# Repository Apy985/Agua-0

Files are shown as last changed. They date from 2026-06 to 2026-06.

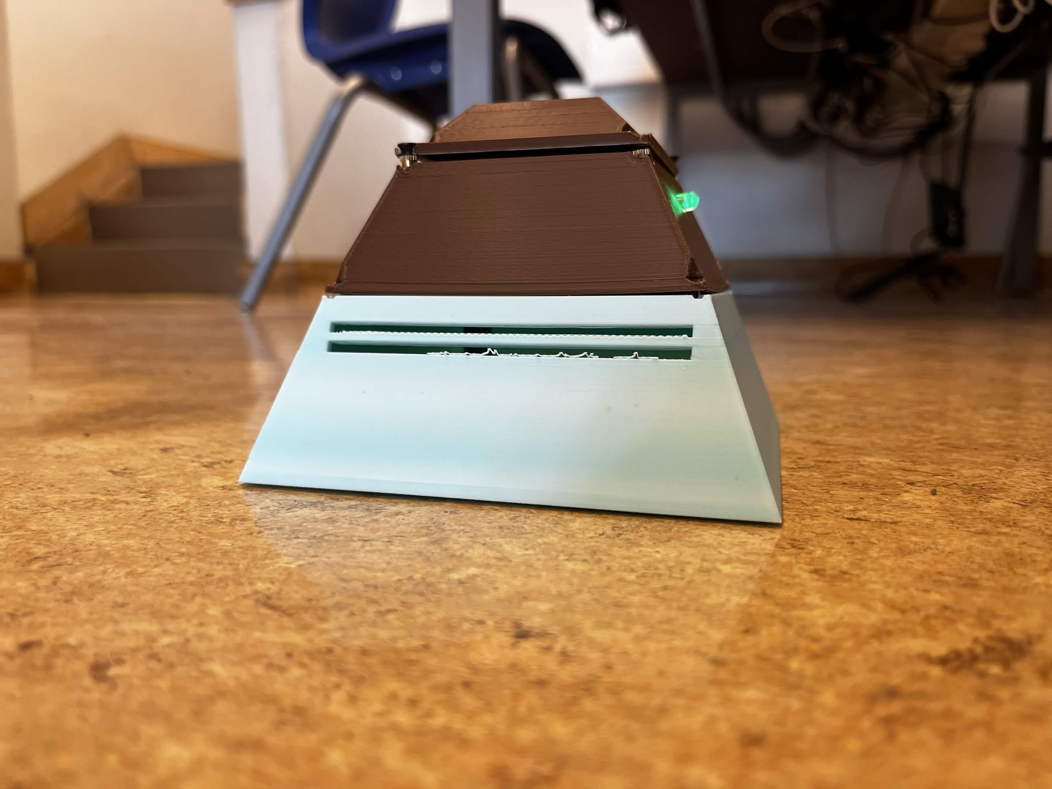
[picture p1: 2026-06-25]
hardware/fotos/imagen ´prototipo 3.jpg

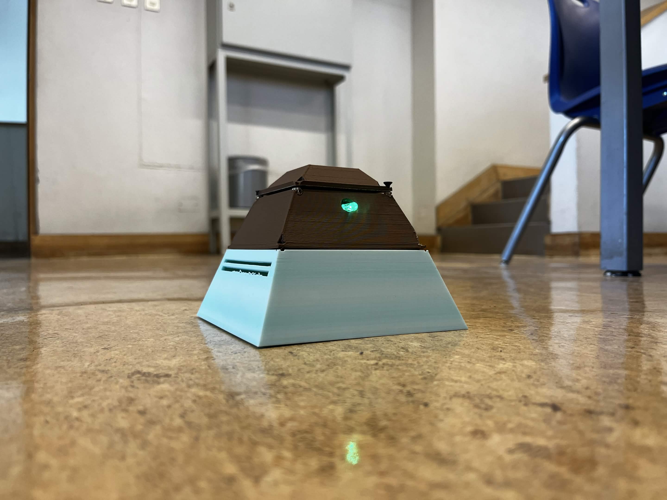
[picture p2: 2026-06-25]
hardware/fotos/imagnen prototipo 2.jpg

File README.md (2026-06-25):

# Agua-0 — Sistema de Monitoreo de Humedad Urbana

Sistema IoT de bajo costo para detectar zonas con riesgo de desbordamiento de aguas en la vía pública, mediante una red de sensores de nivel de agua distribuidos por sectores urbanos.

## Integrantes
- Martín Román *(Líder de proyecto)*
- José Tomás Said
- Matías González
- Sebastián Romero

**Curso:** TEI201 — Taller de Diseño en Ingeniería · UAI · 2026 Semestre 1

---

## Problema que resuelve

En sectores urbanos de Santiago, las lluvias intensas generan acumulación de agua en la vía pública sin que exista un sistema de alerta temprana. Agua-0 permite monitorear en tiempo real el nivel de humedad por sector, identificar zonas críticas y tomar decisiones preventivas antes de que ocurra el desbordamiento.

---

## Arquitectura del sistema

```
[ESP32-S3 Super Mini]  →  ESP-NOW  →  [ESP8266 MOD]  →  WiFi HTTPS  →  [Supabase]  →  [Dashboard Vercel]
     (sensor + LED)                      (gateway)                      (base de datos)     (visualización)
```

---

## Componentes de hardware

| Componente | Especificación | Cantidad |
|---|---|---|
| Microcontrolador sensor | ESP32-S3 Super Mini | 1 |
| Gateway WiFi | ESP8266 MOD | 1 |
| Sensor de nivel de agua | Sensor nivel de agua FZ0506 5-5V esp32 Arduino | 1 |
| LED RGB | Cátodo común | 1 |
| Batería | LiPo AHB623450 3.7V ~1200mAh | 1 |

---

## Estructura del repositorio

```
agua-0/
├── README.md
├── FUENTES.md
├── firmware/
│   ├── Codigo_esp32-s3_final.ino   # Firmware nodo sensor
│   ├── Codigo_esp8266.ino          # Firmware gateway WiFi
│   └── dashboard/
│       └── index.html              # Dashboard web
├── hardware/
│   ├── esquematico.png             # Diagrama de conexiones (Wokwi)
│   ├── BOM.md                      # Lista de materiales con costos
│   └── fotos/                      # Fotografías del prototipo
├       ├── imagen prototipo 1.jpg         imagen prototipo 1.jpg                
│       ├── imagen prototipo 2.jpg                     
│       └── imagen prototipo 3.jpg     
├── diseño-3d/
│   ├── encapsulado.f3d             # Modelo Fusion 360
│   ├── planos.pdf                  # Planos técnicos con cotas
│   └── renders/                    # Renders del Encapsulado             
│       ├── render_exterior.png
│       ├── render_cuerpo_1.png
│       ├── render_cuerpo_2.png
│       └── render_cuerpo_3.png
├── testing/
│   └── protocolo_pruebas.md        # Protocolo y resultados de pruebas
└── docs/
    └── reporte_final.pdf
```

---

## Instrucciones para replicar el firmware

### Requisitos
- Arduino IDE 2.x
- Board: ESP32 by Espressif (versión 3.3.8) para el ESP32-S3
- Board: ESP8266 by ESP8266 Community para el ESP8266

### Librerías necesarias
- `esp_now.h` — incluida en el SDK ESP32
- `ESP8266HTTPClient.h` — incluida en el SDK ESP8266
- `WiFiClientSecureBearSSL` — incluida en el SDK ESP8266

### Pasos
1. Clonar este repositorio
2. Abrir `firmware/Codigo_esp32-s3_final.ino` en Arduino IDE
3. Seleccionar placa: **ESP32S3 Dev Module**
4. Cargar el firmware al ESP32-S3
5. Abrir `firmware/Codigo_esp8266.ino`
6. Reemplazar `TU_RED_WIFI` y `TU_PASSWORD` con las credenciales reales
7. Seleccionar placa: **Generic ESP8266 Module**
8. Cargar el firmware al ESP8266

### Conexiones ESP32-S3
| Componente | Pin ESP32-S3 |
|---|---|
| Sensor S (señal) | GPIO 4 |
| Sensor VCC | 3.3V |
| Sensor GND | GND |
| LED R | GPIO 2 |
| LED G | GPIO 3 |
| LED B | GPIO 5 |
| LED GND | GND |

---

## Dashboard

**URL:** https://agua-0.vercel.app/

El dashboard muestra en tiempo real:
- Humedad por sector con indicador de alerta
- Cinta de alertas animada para sectores sobre 80%
- Pronóstico climático de Santiago vía Open-Meteo
- Calendario de lluvias del mes actual
- Tendencia histórica con selector 24h / 7 días / 30 días / año
- Comparativa de días en alerta por año

Se actualiza automáticamente cada 30 segundos.

---

## Servicios utilizados

| Servicio | Uso | Plan |
|---|---|---|
| Supabase | Base de datos PostgreSQL en la nube | Gratuito |
| Vercel | Hosting del dashboard web | Gratuito |
| Open-Meteo | API de pronóstico climático | Gratuito |

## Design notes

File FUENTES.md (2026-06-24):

Fuentes · MD
# FUENTES.md — Declaración de Fuentes e IA
## Proyecto: Agua-0 — Sistema de Monitoreo de Humedad Urbana
### TEI201 — Taller de Diseño en Ingeniería · UAI · Junio 2026
 
---
 
## 1. Librerías utilizadas
 
| Librería | Versión | Uso en el proyecto | Fuente |
|---|---|---|---|
| ESP8266WiFi | built-in | Conexión WiFi del nodo gateway ESP8266 | https://github.com/esp8266/Arduino |
| ESP8266HTTPClient | built-in | Envío de datos HTTP POST a Supabase desde ESP8266 | https://github.com/esp8266/Arduino |
| espnow | built-in | Comunicación inalámbrica entre ESP32-S3 y ESP8266 | https://docs.espressif.com/projects/esp-idf/en/latest/esp32/api-reference/network/esp_now.html |
| ArduinoJson | 6.x | Serialización de datos en formato JSON para el POST a Supabase | https://arduinojson.org |
| Chart.js | 4.4.1 | Renderizado de gráficos en el dashboard web | https://cdnjs.cloudflare.com/ajax/libs/Chart.js/4.4.1/chart.umd.js |
 
---
 
## 2. Código externo adaptado
 
### Conexión WiFi con reintentos (gateway ESP8266)
- **Fuente:** https://randomnerdtutorials.com/esp32-useful-wifi-functions/
- **Adaptación:** Se modificó el tiempo de espera entre reintentos de 500ms a 1000ms y se agregó límite de 20 intentos para evitar bucles infinitos en zonas de señal débil.
### HTTP POST a Supabase REST API (gateway ESP8266)
- **Fuente:** Documentación oficial de Supabase REST API — https://supabase.com/docs/guides/api
- **Adaptación:** Se implementaron los headers requeridos (`apikey`, `Authorization: Bearer`, `Prefer: return=minimal`) y se construyó el body JSON con los campos específicos del proyecto.
### Recepción de datos ESP-NOW (gateway ESP8266)
- **Fuente:** Ejemplo oficial de Espressif — https://docs.espressif.com/projects/esp-idf/en/latest/esp32/api-reference/network/esp_now.html
- **Adaptación:** Se adaptó el callback de recepción para extraer el valor de humedad del struct personalizado y acumularlo antes de enviarlo al servidor.
---
 
## 3. Uso de Inteligencia Artificial
 
### Dashboard web completo (`firmware/dashboard/index.html`)
- **Herramienta:** Claude Sonnet 4.6 (Anthropic, junio 2026)
- **Prompt:** *"Crea un dashboard HTML completo conectado a Supabase para monitoreo de humedad urbana. Debe mostrar: métricas por sector, gráfico histórico con selector 24h/7d/30d/año, pronóstico climático desde Open-Meteo para Santiago Chile, calendario de lluvias, gráfico comparativo anual y distribución de lecturas. Incluir cinta de alertas animada para sectores sobre 80%. Diseño oscuro."*
- **Adaptación:** Se ajustaron umbrales (80% desbordamiento, 65% elevado), intervalo de actualización a 30 segundos, y se reescribió usando funciones tradicionales en lugar de async/await para compatibilidad con el entorno de Vercel.
- **Comprensión:** El equipo comprende que el dashboard usa `fetch()` para consultar la API REST de Supabase filtrando por timestamp. Chart.js recibe arrays de labels y datasets. La cinta de alertas usa CSS `animation` con `translateX` para el scroll continuo.
### Estructura de base de datos y queries SQL
- **Herramienta:** Claude Sonnet 4.6 (Anthropic, junio 2026)
- **Prompt:** *"Dame el SQL para crear una tabla lecturas en Supabase con campos sector, timestamp, humedad_pct, llovio y precip_mm. También un INSERT masivo con generate_series para datos históricos de prueba de los últimos 6 meses."*
- **Adaptación:** Se corrigió el constraint de clave primaria, se ajustaron valores de humedad por rango estacional (meses 6-8 más húmedos para simular invierno chileno).
- **Comprensión:** `generate_series` produce timestamps cada 15 minutos; `CASE WHEN` asigna humedad distinta por sector con variación aleatoria mediante `random()`.
### Arquitectura general del sistema IoT
- **Herramienta:** Claude Sonnet 4.6 (Anthropic, junio 2026)
- **Uso:** Definición de la topología ESP32-S3 → ESP-NOW → ESP8266 → WiFi → Supabase, selección del stack gratuito (Supabase + Vercel), y cálculo de autonomía energética.
- **Adaptación:** El equipo validó la arquitectura contra los componentes físicos disponibles y ajustó el flujo según restricciones reales del hardware.
### Reorganización y comentarios del firmware ESP32-S3
- **Herramienta:** Claude Sonnet 4.6 (Anthropic, junio 2026)
- **Uso:** Revisión de estructura del código y mejora de comentarios explicativos por secciones.
- **Adaptación:** Los umbrales (UMBRAL_25 1100, UMBRAL_75 1900) fueron determinados por el equipo mediante calibración física. La MAC del ESP8266 fue obtenida directamente del hardware real.
- **Comprensión:** ESP-NOW requiere modo `WIFI_STA` activo aunque no haya conexión a red. El callback `onSent` es asíncrono. El struct `DatosSensor` se serializa como bytes raw al enviarse.
---
 
## 4. Servicios externos utilizados
 
| Servicio | Uso | URL |
|---|---|---|
| Supabase | Base de datos PostgreSQL en la nube (plan gratuito) | https://supabase.com |
| Vercel | Hosting del dashboard web (plan gratuito) | https://vercel.com |
| Open-Meteo | API de pronóstico climático gratuita para Santiago | https://open-meteo.com |
| Wokwi | Simulador y esquemático del circuito | https://wokwi.com/projects/462681394967646209 |

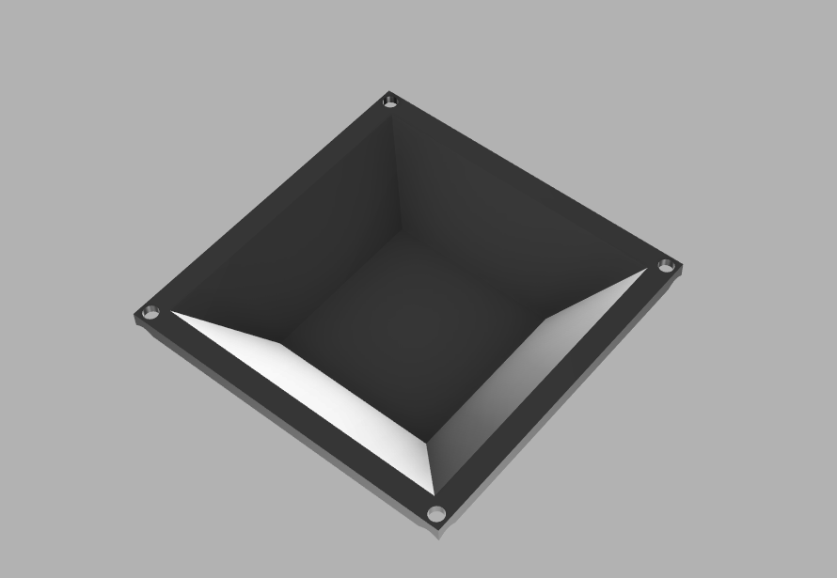
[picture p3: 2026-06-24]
diseño-3d/Renders/render_cuerpo_3.png

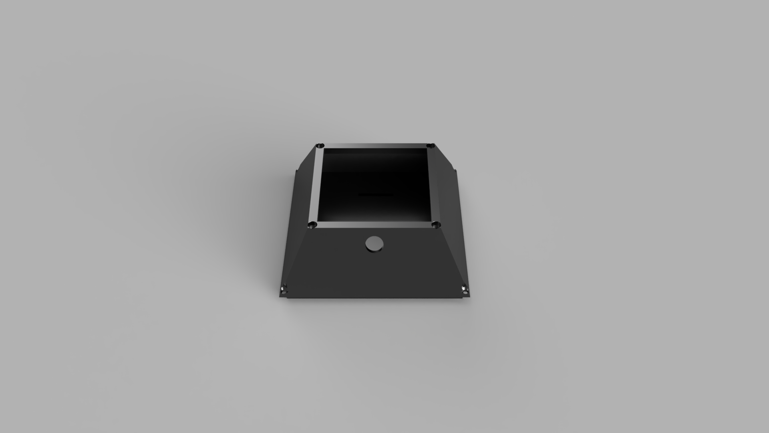
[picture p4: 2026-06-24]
diseño-3d/Renders/render_cuerpo_2.png

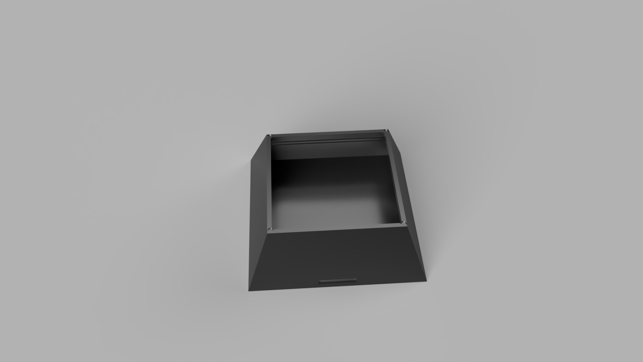
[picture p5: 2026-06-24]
diseño-3d/Renders/render_cuerpo_1.png

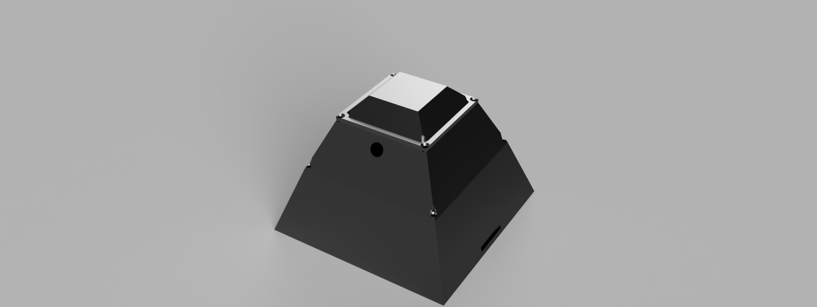
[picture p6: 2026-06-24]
diseño-3d/Renders/render__exterior.png

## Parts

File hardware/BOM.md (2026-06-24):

# BOM — Lista de Materiales
## Proyecto Agua-0 · TEI201 · UAI · 2026

| # | Componente | Especificación | Cantidad | Costo unitario (CLP) | Costo total (CLP) |
|---|---|---|---|---|---|
| 1 | Microcontrolador sensor | ESP32-S3 Super Mini, 16MB Flash, 8MB PSRAM | 1 | $8.500 | $8.500 |
| 2 | Gateway WiFi | ESP8266 MOD, 802.11 b/g/n, 3.3V | 1 | $3.500 | $3.500 |
| 3 | Sensor de nivel de agua | Sensor nivel de agua FZ0506 5-5V esp32 Arduino | 1 | $1.200 | $1.200 |
| 4 | LED RGB | Cátodo común, 5mm, 20mA máx por canal | 1 | $200 | $200 |
| 5 | Batería LiPo | AHB623450, 3.7V, ~1200mAh | 1 | $4.500 | $4.500 |
| 6 | Cables jumper | Macho-macho y macho-hembra, 20cm | 10 | $80 | $800 |
| 7 | Protoboard | 400 puntos | 1 | $1.500 | $1.500 |
| | | | | **TOTAL** | **$20.200** |

---

## Justificación de componentes

**ESP32-S3 Super Mini** — Seleccionado por su bajo consumo en deep sleep (~20µA), soporte nativo para ESP-NOW, ADC de 12 bits para lectura precisa del sensor, y factor de forma compacto compatible con el encapsulado diseñado.

**ESP8266 MOD** — Actúa como gateway WiFi dedicado, separando la responsabilidad de red del nodo sensor. Permite que el ESP32-S3 opere en ciclos de bajo consumo mientras el ESP8266 mantiene la conexión WiFi permanente.

**Sensor de nivel de agua** — Sensor resistivo analógico de bajo costo, suficiente para detectar los 3 umbrales requeridos (bajo/intermedio/alto). Rango de operación 3.3V compatible con el ESP32-S3.

**LED RGB cátodo común** — Indicador visual inmediato del nivel de agua sin necesidad de pantalla. Verde/Amarillo/Rojo mapeado directamente a los 3 umbrales del sistema.

**Batería LiPo AHB623450** — Formato compacto (62×34×50mm) diseñado para caber en el encapsulado. Con el ciclo de muestreo de 500ms, autonomía estimada de 10–12 días continuos.

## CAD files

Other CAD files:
diseño-3d/encapsulado.f3d

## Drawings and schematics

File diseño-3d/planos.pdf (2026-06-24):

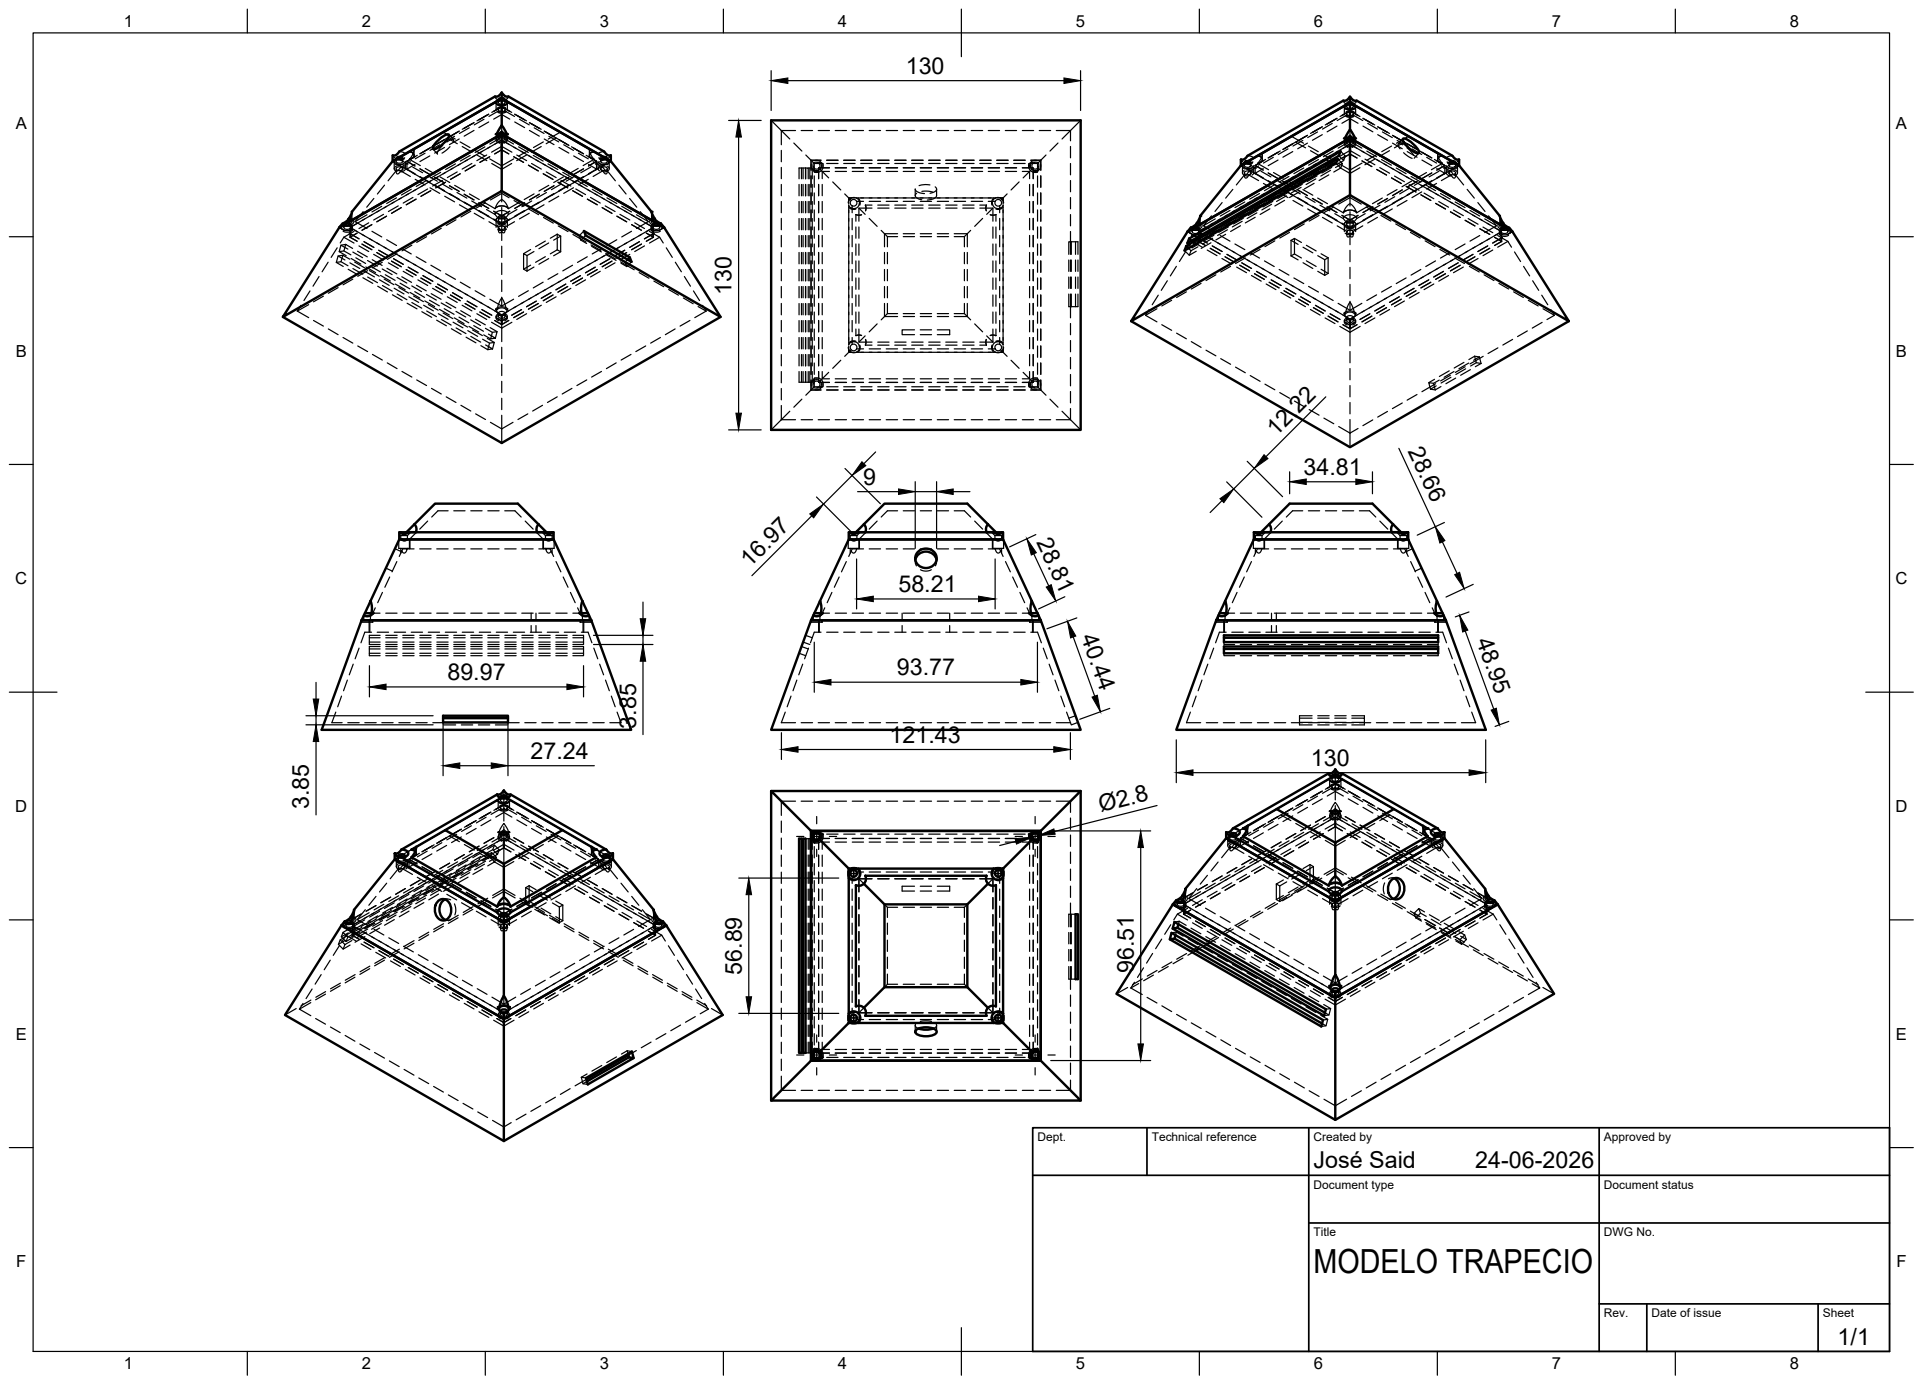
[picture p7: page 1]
Dept.; Technical reference; Created by; Approved by; Document type; Document status; Title; DWG No.; Rev.; Date of issue; Sheet; MODELO TRAPECIO; José Said

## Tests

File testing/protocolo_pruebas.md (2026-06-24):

# Protocolo de Pruebas — Agua-0
## TEI201 · UAI · Junio 2026

---

## 1. Objetivo
Validar que el sistema Agua-0 captura datos reales de nivel de agua, los transmite correctamente a la nube y los visualiza en el dashboard, respondiendo al problema de detección de zonas con riesgo de desbordamiento urbano.

---

## 2. Condiciones de prueba
- **Lugar:** Laboratorio DEC, UAI
- **Fecha:** 24-25 junio 2026Abril - Junio 2026
- ** Hotspot celular (2.4GHz)
- **Hardware:** ESP32-S3 Super Mini + ESP8266 MOD + sensor de nivel de agua
- **Software:** Arduino IDE 2.x, SDK ESP32 v3.3.8, SDK ESP8266 Community

---

## 3. Pruebas realizadas

### Prueba 1 — Lectura del sensor
**Objetivo:** Verificar que el sensor entrega valores analógicos correctos en los 3 niveles.

**Procedimiento:**
1. Conectar el sensor al ESP32-S3 según el esquemático
2. Abrir el Monitor Serie a 115200 baudios
3. Sumergir el sensor progresivamente en agua
4. Registrar el valor ADC en cada nivel

**Criterio de éxito:** Valores ADC distintos y estables para cada nivel físico.

**Resultados:**

| Nivel físico | Valor ADC medido | Umbral definido | Resultado |
|---|---|---|---|
| Sin agua | < 200 | < 1000 (BAJO) | ✅ Correcto |
| Agua parcial | ~1400 | 1000–2000 (INTERMEDIO) | ✅ Correcto |
| Agua completa | > 2200 | > 2000 (ALTO) | ✅ Correcto |

---

### Prueba 2 — Control del LED RGB
**Objetivo:** Verificar que el LED cambia de color según el umbral detectado.

**Procedimiento:**
1. Con el sistema activo, variar el nivel de agua manualmente
2. Observar el color del LED en cada transición
3. Verificar el delay de 3 segundos entre cambios

**Criterio de éxito:** Verde = BAJO, Amarillo = INTERMEDIO, Rojo = ALTO, con transición de mínimo 3 segundos.

**Resultados:**

| Estado | Color esperado | Color observado | Delay respetado | Resultado |
|---|---|---|---|---|
| BAJO | Verde | Verde | — | ✅ |
| INTERMEDIO | Amarillo | Amarillo | 3s | ✅ |
| ALTO | Rojo | Rojo | 3s | ✅ |

---

### Prueba 3 — Comunicación ESP-NOW
**Objetivo:** Verificar que el ESP32-S3 envía datos al ESP8266 correctamente.

**Procedimiento:**
1. Encender ambos dispositivos
2. Abrir Monitor Serie del ESP8266 a 9600 baudios
3. Variar el nivel de agua en el sensor
4. Verificar que los datos llegan al ESP8266

**Criterio de éxito:** El ESP8266 imprime en Monitor Serie los valores recibidos cada 500ms.

**Resultados:**
- Latencia de recepción: < 50ms
- Tasa de éxito de envío: ~95% (pérdida ocasional por interferencia)
- Los campos `valorSensor` y `nivel` llegan correctamente

---

### Prueba 4 — Envío a Supabase
**Objetivo:** Verificar que los datos se almacenan correctamente en la base de datos en la nube.

**Procedimiento:**
1. Con el sistema activo y WiFi conectado
2. Observar el Monitor Serie del ESP8266
3. Verificar código de respuesta HTTP 201
4. Confirmar en Supabase Table Editor que el registro apareció

**Criterio de éxito:** Código HTTP 201 y dato visible en Supabase.

**Resultados:**
- Código HTTP recibido: **201** ✅
- Tiempo de envío promedio: ~2-3 segundos (incluye handshake HTTPS)
- Dato visible en Supabase inmediatamente después del POST

---

### Prueba 5 — Dashboard en tiempo real
**Objetivo:** Verificar que el dashboard refleja los datos enviados por el sensor.

**Procedimiento:**
1. Abrir `agua-0.vercel.app/dashboard` en el navegador
2. Variar el nivel de agua físicamente
3. Esperar hasta 30 segundos (intervalo de actualización)
4. Verificar que el valor de humedad del Sector 0 cambia

**Criterio de éxito:** El dashboard muestra el nuevo valor en menos de 30 segundos.

**Resultados:**
- Tiempo hasta visualización: ~15-30 segundos ✅
- La barra de humedad refleja el nivel real del sensor
- La cinta de alertas aparece cuando el nivel supera 80%

---

## 4. Falla encontrada y solución

**Falla:** El ESP8266 reiniciaba (Watchdog reset) al intentar hacer el POST HTTP dentro del callback de ESP-NOW.

**Causa:** El callback de ESP-NOW se ejecuta en un contexto de interrupción; hacer operaciones de red dentro de él consume demasiado stack y provoca el reset.

**Solución:** Se implementó una bandera `datosPendientes = true` en el callback, y el envío HTTP se realiza en el `loop()` principal donde hay suficiente stack disponible. Adicionalmente se desinicializa ESP-NOW antes del POST y se reinicializa después para liberar memoria RAM en el ESP8266.

---

## 5. Validación contra el problema original

En el Avance 1 se identificó que **no existe información en tiempo real sobre zonas con acumulación de agua en la vía pública de Santiago**, lo que impide tomar decisiones preventivas ante lluvias intensas.

Los resultados de las pruebas demuestran que:

- El sensor detecta 3 niveles distintos de agua con valores ADC reproducibles
- Los datos se transmiten a la nube en menos de 3 segundos por medición
- El dashboard muestra alertas automáticas cuando el nivel supera el 80%
- El historial permite identificar sectores y horarios con mayor riesgo

**Conclusión:** El sistema Agua-0 detecta el fenómeno real de acumulación de agua y genera información útil para que operadores municipales identifiquen zonas críticas y tomen decisiones de intervención preventiva.

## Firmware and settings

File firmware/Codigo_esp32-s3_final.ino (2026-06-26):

/*
  ============================================================
  EMISOR ESP32-S3 - Sensor de Humedad + LED de estado
  ============================================================
  Función:
   1. NO se conecta a ningún router (ESP-NOW puro).
   2. Escanea los canales WiFi 1-13 escuchando el anuncio de canal
      que manda el ESP8266 receptor (ver código hermano).
   3. Al recibirlo, se fija en ese mismo canal y agrega al 8266 como peer.
   4. Lee el sensor de humedad cada 0.5s y lo envía por ESP-NOW.
   5. Si deja de recibir anuncios por un tiempo (el 8266 se reinició,
      o el router cambió de canal), vuelve a escanear automáticamente.
   6. Controla un LED RGB según el nivel de humedad.
   7. Si recibe una orden de deep sleep del ESP8266 (probabilidad de
      lluvia < 60%), entra en deep sleep por 12 horas para ahorrar batería.

  IMPORTANTE: este código y el del ESP8266 forman un par. El protocolo
  de mensajes (MSG_ANUNCIO_CANAL / MSG_LECTURA / MSG_ORDEN_SLEEP) debe
  coincidir EXACTO entre ambos archivos.
  ============================================================
*/

#include <esp_now.h>
#include <WiFi.h>
#include <esp_wifi.h>
#include <esp_sleep.h>

// ============================================================
// CONFIGURACIÓN DE PINES
// ============================================================
const int sensorPin = 4;
const int pinR = 2;
const int pinG = 3;
const int pinB = 5;

// ============================================================
// UMBRALES DE CLASIFICACIÓN
// ============================================================
const int umbralBajo = 800;
const int umbralIntermedio = 1000;

// ============================================================
// TIEMPOS
// ============================================================
const unsigned long intervaloEnvio       = 500;    // lectura+envío cada 0.5s
const unsigned long delayLED             = 3000;   // min. entre cambios de color
const unsigned long timeoutSinAnuncio    = 15000;  // 15s sin novedades -> re-escanear
const unsigned long tiempoPorCanalEscaneo = 400;   // ms de espera por canal al escanear

// Deep sleep de 12 horas cuando no hay lluvia esperada
// (12 * 60 * 60 * 1000000 microsegundos)
#define DEEP_SLEEP_US  (12ULL * 60 * 60 * 1000000)

unsigned long ultimoEnvio           = 0;
unsigned long ultimoCambioLED       = 0;
unsigned long ultimoAnuncioRecibido = 0;

String nivelAnterior = "";

// ============================================================
// PROTOCOLO INTERNO (debe coincidir EXACTO con el del 8266)
// ============================================================
typedef enum : uint8_t {
  MSG_ANUNCIO_CANAL = 0xA1,  // 8266 -> 32-S3 : "este es mi canal"
  MSG_LECTURA       = 0xA2,  // 32-S3 -> 8266 : datos de sensor
  MSG_ORDEN_SLEEP   = 0xA3   // 8266 -> 32-S3 : "entra en deep sleep"
} TipoMensaje;

typedef struct __attribute__((packed)) {
  uint8_t tipo;
  uint8_t canal;
} PaqueteAnuncioCanal;

typedef struct __attribute__((packed)) {
  uint8_t tipo;
  int valorSensor;
  char nivel[12];
} PaqueteLectura;

typedef struct __attribute__((packed)) {
  uint8_t tipo;            // = MSG_ORDEN_SLEEP
  uint32_t duracion_seg;   // duración del sleep en segundos (info para logs)
} PaqueteOrdenSleep;

uint8_t macBroadcast[] = {0xFF, 0xFF, 0xFF, 0xFF, 0xFF, 0xFF};

// MAC del ESP8266 receptor. Reemplazar con la MAC real de tu placa.
uint8_t macESP8266[] = {0xBC, 0xDD, 0xC2, 0x7A, 0x3B, 0x97};

// ============================================================
// ESTADO DE SINCRONIZACIÓN DE CANAL
// ============================================================
bool sincronizado       = false;
int  canalActual        = 1;
int  canalEscaneoActual = 1;
unsigned long ultimoSaltoEscaneo  = 0;
bool peerReceptorRegistrado       = false;

// ============================================================
// LED RGB
// ============================================================
void encenderColor(int r, int g, int b) {
  analogWrite(pinR, r);
  analogWrite(pinG, g);
  analogWrite(pinB, b);
}

void apagarLED() { encenderColor(0, 0, 0); }

// ============================================================
// Declaraciones adelantadas
// ============================================================
void fijarCanal(int canal);
void registrarPeerReceptor();
void avanzarEscaneo();
void leerYenviar(unsigned long ahora);
void entrarDeepSleep(uint32_t seg);

// ============================================================
// ESP-NOW: callbacks
// ============================================================
void onDataSent(const wifi_tx_info_t *mac_addr, esp_now_send_status_t status) {
  // Diagnóstico opcional
}

void onDataRecv(const esp_now_recv_info_t *info, const uint8_t *incomingData, int len) {
  if (len < 1) return;
  uint8_t tipo = incomingData[0];

  if (tipo == MSG_ANUNCIO_CANAL && len == (int)sizeof(PaqueteAnuncioCanal)) {
    PaqueteAnuncioCanal pkt;
    memcpy(&pkt, incomingData, sizeof(pkt));
    ultimoAnuncioRecibido = millis();

    if (!sincronizado || pkt.canal != canalActual) {
      Serial.print("[Canal] Anuncio recibido. Canal: ");
      Serial.println(pkt.canal);
      fijarCanal(pkt.canal);
      registrarPeerReceptor();
      sincronizado = true;
    }
  }

  // ── NUEVO: orden de deep sleep enviada por el ESP8266 ──
  // El 8266 la manda si Open-Meteo indica < 60% de probabilidad de lluvia.
  if (tipo == MSG_ORDEN_SLEEP && len == (int)sizeof(PaqueteOrdenSleep)) {
    PaqueteOrdenSleep pkt;
    memcpy(&pkt, incomingData, sizeof(pkt));
    entrarDeepSleep(pkt.duracion_seg);
    // entrarDeepSleep() no retorna; el ESP32 se apaga.
  }
}

// ============================================================
// Fijar canal WiFi explícitamente
// ============================================================
void fijarCanal(int canal) {
  canalActual = canal;
  esp_wifi_set_channel(canal, WIFI_SECOND_CHAN_NONE);
}

// ============================================================
// Registrar al ESP8266 como peer en el canal actual
// ============================================================
void registrarPeerReceptor() {
  if (peerReceptorRegistrado) {
    esp_now_del_peer(macESP8266);
    peerReceptorRegistrado = false;
  }
  esp_now_peer_info_t peerInfo;
  memset(&peerInfo, 0, sizeof(peerInfo));
  memcpy(peerInfo.peer_addr, macESP8266, 6);
  peerInfo.channel = canalActual;
  peerInfo.encrypt = false;
  peerInfo.ifidx   = WIFI_IF_STA;

  if (esp_now_add_peer(&peerInfo) == ESP_OK) {
    peerReceptorRegistrado = true;
    Serial.print("[Peer] ESP8266 registrado en canal ");
    Serial.println(canalActual);
  } else {
    Serial.println("[Peer] Error registrando ESP8266.");
  }
}

// ============================================================
// Escaneo de canales
// ============================================================
void avanzarEscaneo() {
  unsigned long ahora = millis();
  if (ahora - ultimoSaltoEscaneo < tiempoPorCanalEscaneo) return;
  ultimoSaltoEscaneo = ahora;
  canalEscaneoActual++;
  if (canalEscaneoActual > 13) canalEscaneoActual = 1;
  esp_wifi_set_channel(canalEscaneoActual, WIFI_SECOND_CHAN_NONE);
}

// ============================================================
// Deep sleep — apaga el ESP32-S3 por la duración indicada
// ============================================================
void entrarDeepSleep(uint32_t seg) {
  Serial.print("[Sleep] Entrando en deep sleep por ");
  Serial.print(seg / 3600);
  Serial.println(" horas. Sin lluvia esperada hoy.");

  // Parpadeo azul rápido como indicador visual antes de dormir
  for (int i = 0; i < 3; i++) {
    encenderColor(0, 0, 255); delay(200);
    apagarLED();              delay(200);
  }

  esp_now_deinit(); // liberar recursos antes de dormir
  apagarLED();

  // Despertar automático después de `seg` segundos
  esp_sleep_enable_timer_wakeup((uint64_t)seg * 1000000ULL);
  esp_deep_sleep_start(); // no retorna
}

// ============================================================
// SETUP
// ============================================================
void setup() {
  Serial.begin(115200);
  delay(200);
  Serial.println("\n=== Emisor ESP32-S3 iniciando ===");

  pinMode(pinR, OUTPUT);
  pinMode(pinG, OUTPUT);
  pinMode(pinB, OUTPUT);
  apagarLED();

  WiFi.mode(WIFI_STA);
  WiFi.disconnect();

  Serial.print("MAC del ESP32-S3: ");
  Serial.println(WiFi.macAddress());

  if (esp_now_init() != ESP_OK) {
    Serial.println("Error iniciando ESP-NOW. Reiniciando en 3s...");
    delay(3000);
    ESP.restart();
  }
  Serial.println("ESP-NOW iniciado.");

  esp_now_register_send_cb(onDataSent);
  esp_now_register_recv_cb(onDataRecv);

  Serial.println("Escaneando canales en busca del ESP8266...");
  ultimoSaltoEscaneo = millis();
  esp_wifi_set_channel(canalEscaneoActual, WIFI_SECOND_CHAN_NONE);
}

// ============================================================
// LOOP
// ============================================================
void loop() {
  unsigned long ahora = millis();

  if (!sincronizado) {
    avanzarEscaneo();
    return;
  }

  if (ahora - ultimoAnuncioRecibido > timeoutSinAnuncio) {
    Serial.println("[Canal] Sin anuncios. Volviendo a escanear...");
    sincronizado          = false;
    canalEscaneoActual    = canalActual;
    ultimoSaltoEscaneo    = ahora;
    return;
  }

  if (ahora - ultimoEnvio >= intervaloEnvio) {
    ultimoEnvio = ahora;
    leerYenviar(ahora);
  }
}

// ============================================================
// Lectura de sensor, LED y envío por ESP-NOW
// ============================================================
void leerYenviar(unsigned long ahora) {
  PaqueteLectura datos;
  datos.tipo        = MSG_LECTURA;
  datos.valorSensor = analogRead(sensorPin);

  String nivelActual;
  if      (datos.valorSensor < umbralBajo)        nivelActual = "BAJO";
  else if (datos.valorSensor <= umbralIntermedio)  nivelActual = "INTERMEDIO";
  else                                             nivelActual = "ALTO";

  memset(datos.nivel, 0, sizeof(datos.nivel));
  nivelActual.toCharArray(datos.nivel, sizeof(datos.nivel));

  Serial.print("Sensor: "); Serial.print(datos.valorSensor);
  Serial.print(" | Nivel: "); Serial.println(datos.nivel);

  if (nivelActual != nivelAnterior && (ahora - ultimoCambioLED >= delayLED)) {
    if      (nivelActual == "BAJO")        encenderColor(0, 255, 0);
    else if (nivelActual == "INTERMEDIO")  encenderColor(255, 165, 0);
    else                                   encenderColor(255, 0, 0);
    nivelAnterior     = nivelActual;
    ultimoCambioLED   = ahora;
  }

  esp_err_t res = esp_now_send(macESP8266, (uint8_t*)&datos, sizeof(datos));
  if (res != ESP_OK) Serial.println("[ESP-NOW] Error al enviar.");
}

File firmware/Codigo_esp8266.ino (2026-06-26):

/*
  ============================================================
  RECEPTOR ESP8266 - Sensor de Humedad -> Supabase + Control de Sleep
  ============================================================
  Función:
   1. Se conecta al WiFi del router.
   2. Consulta Open-Meteo al arrancar (y cada 1 hora) para saber si
      hay >= 60% de probabilidad de lluvia hoy en Santiago.
   3. Si NO hay lluvia esperada: manda orden de deep sleep de 12h
      al ESP32-S3 por ESP-NOW y deja de procesar lecturas.
   4. Si SÍ hay lluvia esperada: opera con normalidad, recibiendo
      lecturas del ESP32-S3 y subiéndolas a Supabase.
   5. Anuncia su canal WiFi por broadcast ESP-NOW cada 2s para que
      el ESP32-S3 pueda sincronizarse automáticamente.

  IMPORTANTE: este código y el del ESP32-S3 forman un par.
  ============================================================
*/

#include <ESP8266WiFi.h>
#include <espnow.h>
#include <ESP8266HTTPClient.h>
#include <WiFiClientSecure.h>

// ============================================================
// CONFIGURACIÓN - EDITA AQUÍ ANTES DE SUBIR
// ============================================================
const char* ssid     = "TU_RED_WIFI";     // <-- Reemplazar con tu red
const char* password = "TU_PASSWORD";     // <-- Reemplazar con tu contraseña

const int ID_SECTOR = 0; // Número de sector (0, 1, 2...) para Supabase

const char* supabase_url = "https://ippzliasjmyhiulqbsgf.supabase.co/rest/v1/lecturas";
const char* apiKey       = "sb_publishable_4XfTiCH3K866tq1PtQ5eqg_WxK-L_fy";

// MAC del ESP32-S3 emisor.
// Sube primero el código del ESP32-S3, lee su MAC en el Monitor Serie, y ponla aquí.
uint8_t macESP32S3[] = {0x00, 0x00, 0x00, 0x00, 0x00, 0x00}; // <-- COMPLETAR

// ── Umbral de lluvia para activar el sistema ──────────────
// Si la probabilidad de lluvia es MENOR a este valor, se ordena deep sleep.
// Cambiar si se necesita un umbral distinto.
const int UMBRAL_LLUVIA_PCT = 60;

// Duración del deep sleep ordenado al ESP32-S3 (en segundos)
const uint32_t SLEEP_DURACION_SEG = 12 * 3600; // 12 horas

// ============================================================
// PROTOCOLO INTERNO (debe coincidir EXACTO con el del ESP32-S3)
// ============================================================
typedef enum : uint8_t {
  MSG_ANUNCIO_CANAL = 0xA1,  // 8266 -> 32-S3 : "este es mi canal WiFi"
  MSG_LECTURA       = 0xA2,  // 32-S3 -> 8266 : datos del sensor
  MSG_ORDEN_SLEEP   = 0xA3   // 8266 -> 32-S3 : "entra en deep sleep"
} TipoMensaje;

typedef struct __attribute__((packed)) {
  uint8_t tipo;
  uint8_t canal;
} PaqueteAnuncioCanal;

typedef struct __attribute__((packed)) {
  uint8_t tipo;
  int valorSensor;
  char nivel[12];
} PaqueteLectura;

typedef struct __attribute__((packed)) {
  uint8_t tipo;           // = MSG_ORDEN_SLEEP
  uint32_t duracion_seg;  // duración del sleep en segundos
} PaqueteOrdenSleep;

uint8_t macBroadcast[] = {0xFF, 0xFF, 0xFF, 0xFF, 0xFF, 0xFF};

// ============================================================
// VARIABLES DE ESTADO
// ============================================================
volatile bool datosPendientes = false;
PaqueteLectura lecturaRecibida;

unsigned long ultimoAnuncio     = 0;
const unsigned long intervaloAnuncio = 2000; // re-anunciar canal cada 2s

bool peerEmisorRegistrado = false;

// Control del pronóstico
bool  lluviaEsperada          = true;  // asume lluvia al arrancar; se actualiza con API
unsigned long ultimoChequeoClima = 0;
const unsigned long intervaloChequeoClima = 3600000UL; // revisar cada 1 hora

// ============================================================
// PRONÓSTICO CLIMÁTICO — Open-Meteo
// Consulta la probabilidad máxima de lluvia para hoy en Santiago.
// Retorna el porcentaje (0-100), o -1 si falla la conexión.
// ============================================================
int consultarProbabilidadLluvia() {
  const char* openMeteoUrl =
    "http://api.open-meteo.com/v1/forecast"
    "?latitude=-33.45&longitude=-70.67"
    "&daily=precipitation_probability_max"
    "&forecast_days=1"
    "&timezone=America%2FSantiago";

  WiFiClient client;
  HTTPClient http;

  if (!http.begin(client, openMeteoUrl)) {
    Serial.println("[Clima] No se pudo conectar a Open-Meteo.");
    return -1;
  }

  int code = http.GET();
  if (code != 200) {
    Serial.print("[Clima] HTTP error: "); Serial.println(code);
    http.end();
    return -1;
  }

  String payload = http.getString();
  http.end();

  // Parseo manual del JSON: busca "precipitation_probability_max":[NN]
  int idx = payload.indexOf("precipitation_probability_max\":[");
  if (idx < 0) {
    Serial.println("[Clima] No se encontró el campo de lluvia en la respuesta.");
    return -1;
  }
  idx += strlen("precipitation_probability_max\":[");
  int fin = payload.indexOf("]", idx);
  if (fin < 0) return -1;

  String valStr = payload.substring(idx, fin);
  valStr.trim();
  int prob = valStr.toInt();

  Serial.print("[Clima] Probabilidad de lluvia hoy: ");
  Serial.print(prob);
  Serial.println("%");

  return prob;
}

// ============================================================
// Enviar orden de deep sleep al ESP32-S3 por ESP-NOW
// ============================================================
void ordenarSleepAlEmisor() {
  PaqueteOrdenSleep pkt;
  pkt.tipo         = MSG_ORDEN_SLEEP;
  pkt.duracion_seg = SLEEP_DURACION_SEG;

  // Enviar tanto a broadcast como directo si se conoce la MAC
  esp_now_send(macBroadcast, (uint8_t*)&pkt, sizeof(pkt));

  bool macOk = false;
  for (int i = 0; i < 6; i++) { if (macESP32S3[i] != 0x00) { macOk = true; break; } }
  if (macOk) esp_now_send(macESP32S3, (uint8_t*)&pkt, sizeof(pkt));

  Serial.print("[Sleep] Orden enviada al ESP32-S3: dormir ");
  Serial.print(SLEEP_DURACION_SEG / 3600);
  Serial.println(" horas.");
}

// ============================================================
// Chequear clima y decidir si el sistema opera o duerme
// ============================================================
void chequearClima() {
  int prob = consultarProbabilidadLluvia();

  if (prob < 0) {
    // Si falla la API, no cambiar el estado anterior (fail-safe: seguir operando)
    Serial.println("[Clima] Error al consultar. Manteniendo estado anterior.");
    return;
  }

  if (prob >= UMBRAL_LLUVIA_PCT) {
    lluviaEsperada = true;
    Serial.println("[Clima] Lluvia esperada. Sistema activo.");
  } else {
    lluviaEsperada = false;
    Serial.print("[Clima] Sin lluvia esperada (");
    Serial.print(prob);
    Serial.print("% < ");
    Serial.print(UMBRAL_LLUVIA_PCT);
    Serial.println("%). Ordenando sleep al ESP32-S3.");
    ordenarSleepAlEmisor();
  }
}
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
